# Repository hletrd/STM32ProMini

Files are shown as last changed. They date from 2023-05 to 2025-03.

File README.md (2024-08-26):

# STM32 Pro Mini
- STM32 Pro Mini dev board
  - 17.8 x 33mm size (excluding USB port)
  - 28 GPIOs
- Based on STM32F411CEU6 MCU (100MHz ARM Cortex M4 CPU, 512kB Flash, 128kB SRAM) or STM32F103CxT6 MCU (72MHz ARM Cortex M3 CPU, 64kB/128kB Flash, 20kB SRAM)
  - Virtually support all 48 pin packaged(LQFP48, UFQFPN48, ...) STM32 MCUs.

- Two main devices are being supported as of now, one with STM32F103Cx and the other with STM32F411Cx.

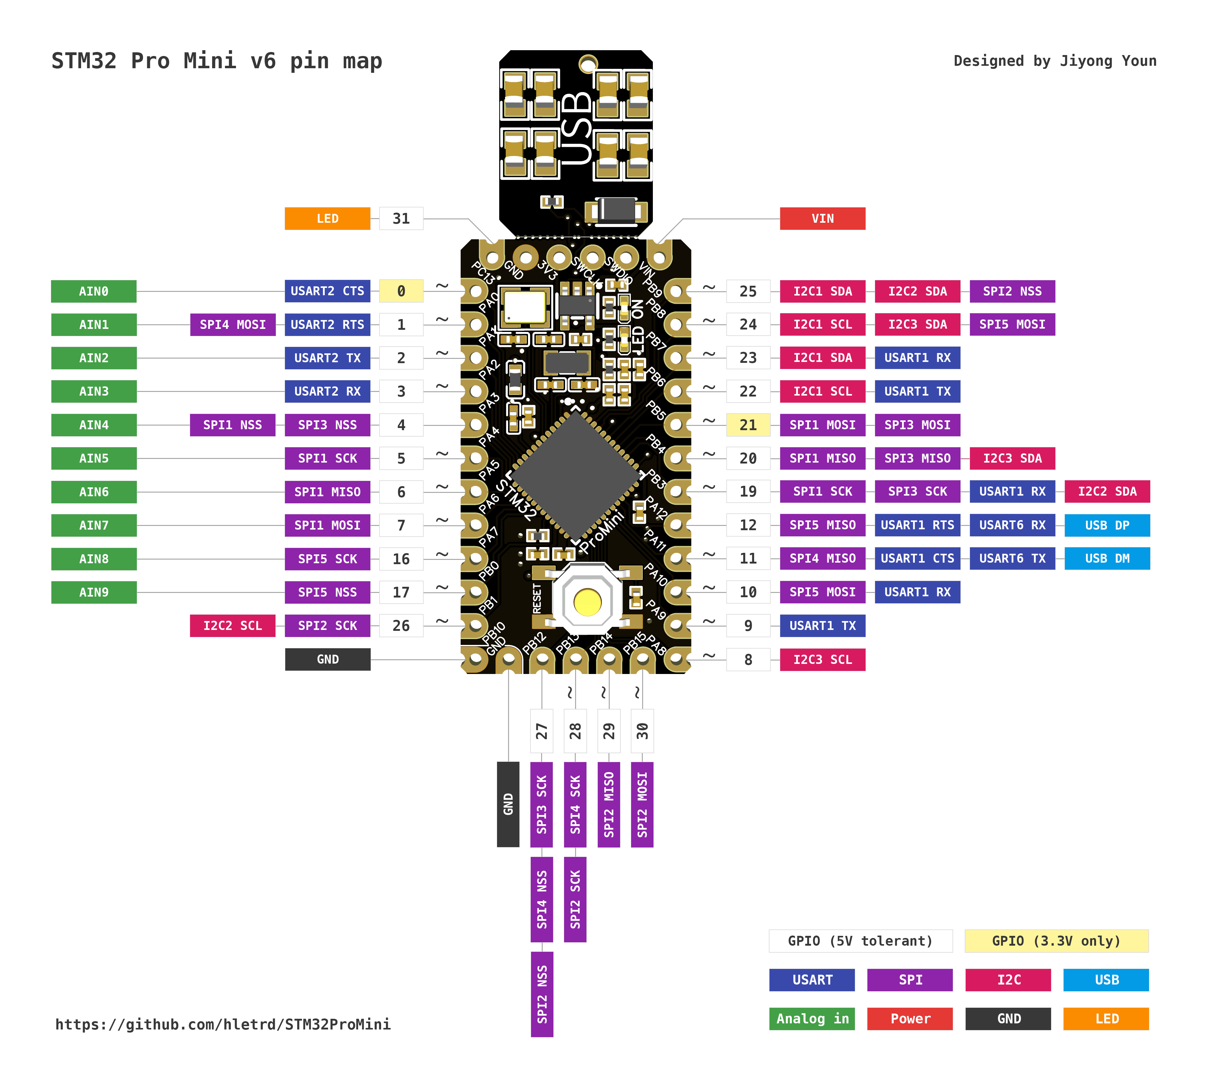
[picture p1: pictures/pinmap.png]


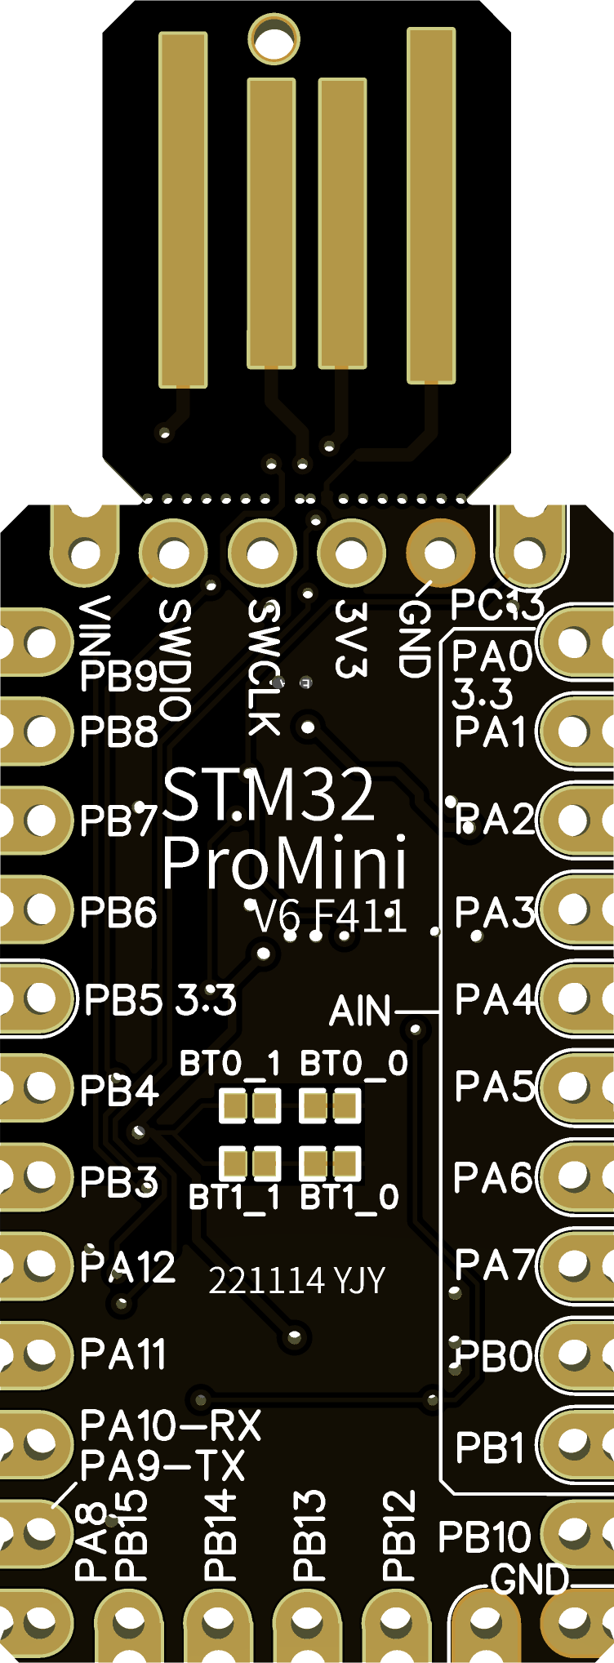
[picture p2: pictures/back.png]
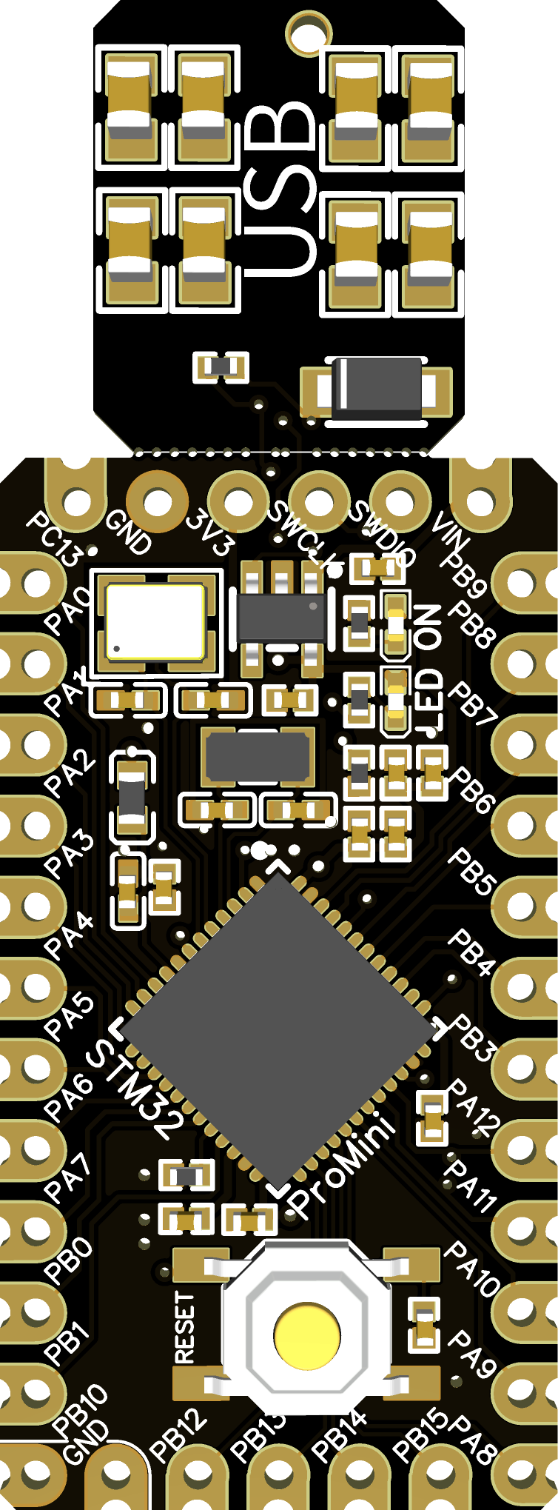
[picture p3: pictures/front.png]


## Getting a board
### Manufacture yourself
  - You can manufacture your own STM32 Pro Mini board with provided files in this repo.
  - Use gerber files in [fabrication/gerber/v6](fabrication/gerber/v6) directory.
  - Use BOM and CPL(Pick&Place) files included in [fabrication](fabrication) directory.
  - Recommended board specifications:
    - Material: FR-4
    - Layers: 2
    - PCB color / silk color: Any
    - Thickness: 1.0mm
    - Surface finish: ENIG
  - All parts can be placed with included BOM/CPL file.

### Get a free board
- Leave an issue and I may send you a free STM32 Pro Mini board.

## Variants and generations
| Gen | CPU | Versions | Features | Board peripheral | Default BOOT configuration |
|-|-|-|-|-|-|
| 1 | STM32F103Cx | V1 (STM32F103C8), V3 (STM32F103CB) | 8MHz ±20ppm HSE, Compatible with common 'Blue Pill' development boards. | None | BOOT0 (0) BOOT1 (0) |
| 2 | STM32F411CE | V2 | 8MHz ±20ppm HSE | Removable USB port | BOOT0 (0) BOOT1 (0) |
| 3 | STM32F411CE | V4, V5, V6 | 12MHz ±10ppm HSE, 32.768kHz ±20ppm LSE (V5, V6), A dedicated analog power rail with noise supression (V5, V6), Castellated edges (V6 only) | Removable USB port | BOOT0 (0) BOOT1 (0) |

### ProMini 3rd gen (F411 (V4, V5, V6))
* Fully redesigned STM32 Pro Mini dev board
* A dedicated analog voltage supply for noise reduction (from V5 and afterwards)
* Ultra low noise, low Iq LDO regulator added to minimize static power draw. (from V5 and afterwards)
* LSE crystal added (from V5 and afterwards)
* PB11 pin is removed and additional GND pin is added.

### ProMini 2nd gen (F411 (V2))
* Based on STM32F411CEU6 MCU 
* PB11 is disabled in this variant, being used to connect a capacitor to supply internal voltage.

#### BOM
* 2.2uF or 4.7uF ceramic capacitor with low ESR have to placed on C13.
* USB pull-up resistor R1 is not needed. (The MCU integrates pull-up resistor for USB D+.)

### ProMini 1st gen (F103 (V1, V3))
* Based on STM32F103C8T6 (V1) / STM32F103CBT6 (V3) MCU
* Compatible with common Blue Pill development board with STM32F103C8T6, except for absence of 32.768kHz crystal.

#### BOM
* C13 is not needed in F103 variant.
* An 1.5k pull-up resistor R1 for USB D+ is needed.

#### Schematic
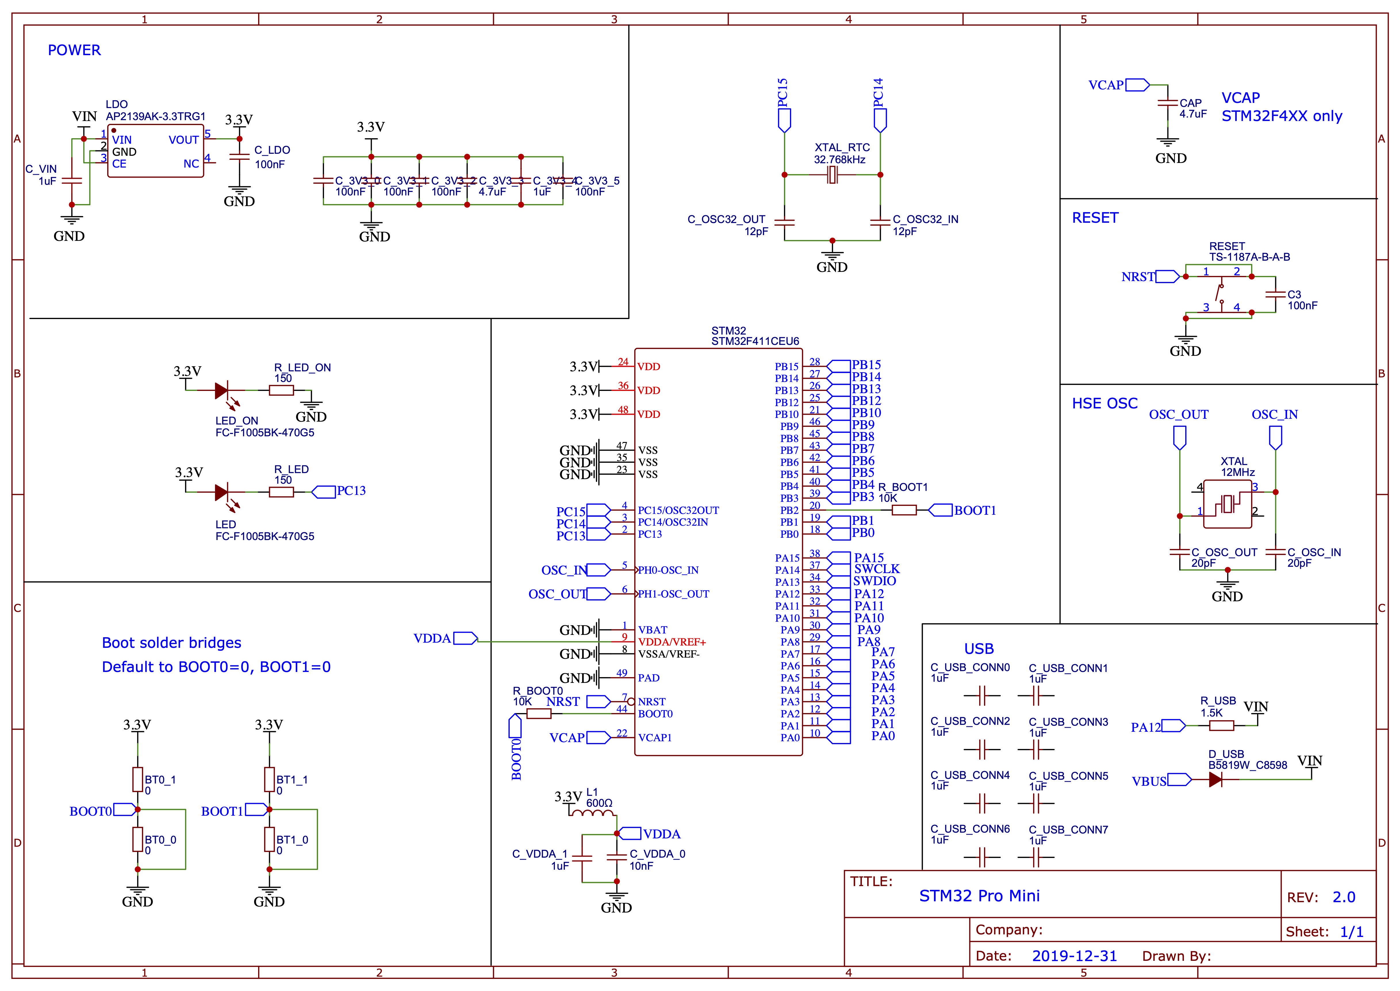
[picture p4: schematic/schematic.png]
Schematic

[PDF version](schematic/schematic.pdf)

#### PCB layout
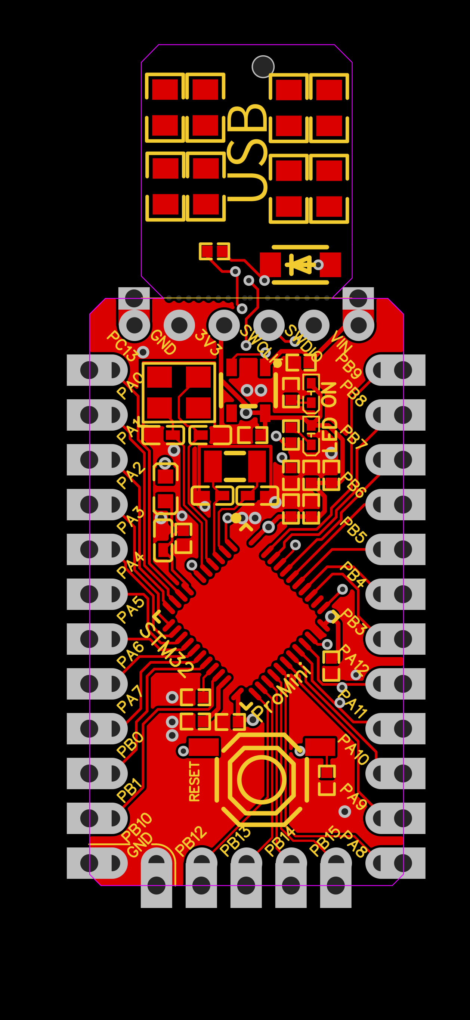
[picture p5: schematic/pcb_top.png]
PCB layout (front)
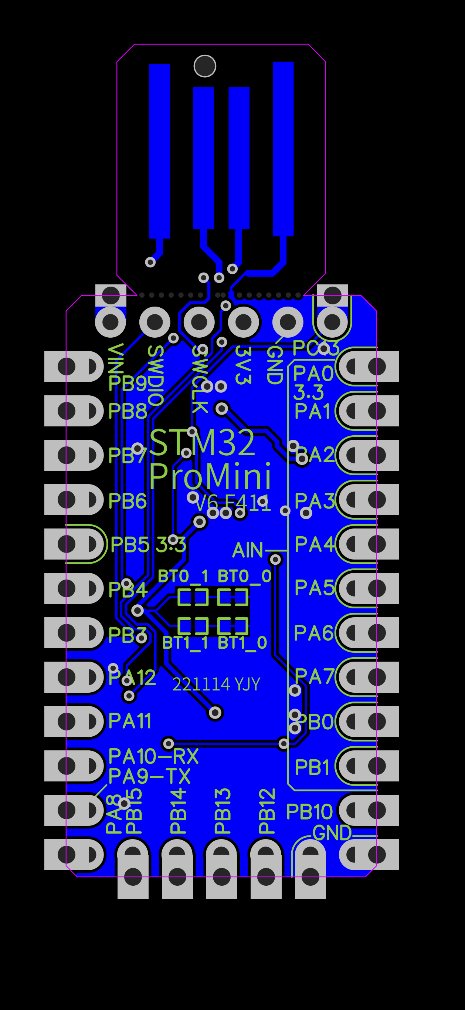
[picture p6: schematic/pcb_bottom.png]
PCB layout (back)


## Setup for Arduino IDE
- Install STM32duino package along with STM32CubeProgrammer.
- Add ```./variants/PROMINI_F411``` (V3-V4) or ```./variants/PROMINI_F411_V5``` (V5, V6)  directory to Arduino IDE ```packages/STM32/hardware/stm32/(version)/variants``` directory.
- Add the content of ```boards-add.txt``` to ```packages/STM32/hardware/stm32/(version)/boards.txt```.

### Programming
- [USB HID bootloader fork](https://github.com/hletrd/STM32_HID_Bootloader) may be used to upload using the integrated USB port.

### Tutorial
- [Getting started with STM32 Pro Mini](TUTORIAL.md)

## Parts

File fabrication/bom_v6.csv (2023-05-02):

ID | Name | Designator | Footprint | Quantity | Manufacturer Part | Manufacturer | Supplier | Supplier Part | Price
1 | 0 | BT0_0,BT0_1,BT1_0,BT1_1 | 0402 | 4 | 0402WGF0000TCE | UniOhm | LCSC | C17168
2 | 1uF | C_USB_CONN4,C_USB_CONN5,C_USB_CONN6,C_USB_CONN7,C_USB_CONN0,C_USB_CONN1,C_USB_CONN2,C_USB_CONN3 | 0805 | 8 | CL21B105KBFNNNE | SAMSUNG | LCSC | C28323 | 0.002
3 | 100nF | C3,C_3V3_0,C_3V3_1,C_3V3_2,C_3V3_5,C_LDO | 0402 | 6 | CL05B104KO5NNNC | SAMSUNG | LCSC | C1525
4 | 4.7uF | CAP,C_3V3_3 | 0402 | 2 | CL05A475MP5NRNC | SAMSUNG | LCSC | C23733 | 0.001
5 | 1uF | C_3V3_4,C_VDDA_1,C_VIN | 0402 | 3 | CL05A105KA5NQNC | SAMSUNG | LCSC | C52923 | 0.001
6 | 12pF | C_OSC32_IN,C_OSC32_OUT | C0402 | 2 | 0402CG120J500NT | FH(风华) | LCSC | C1547
7 | 20pF | C_OSC_IN,C_OSC_OUT | C0402 | 2 | 0402CG200J500NT | FH | LCSC | C1554
8 | 10nF | C_VDDA_0 | C0402 | 1 | CL05B103KB5NNNC | SAMSUNG(三星) | LCSC | C15195
9 | 600Ω | L1 | L0603 | 1 | GZ1608D601TF | Sunlord(顺络) | LCSC | C1002 | 0.001
10 | AP2139AK-3.3TRG1 | LDO | SOT-23-5_L3.0-W1.7-P0.95-LS2.8-BR | 1 | AP2139AK-3.3TRG1 | DIODES | LCSC | C150720 | 0.017
11 | FC-F1005BK-470G5 | LED,LED_ON | LED0402-RD | 2 | FC-F1005BK-470G5 | NATIONSTAR | LCSC | C130724 | 0.006
12 | TS-1187A-B-A-B | RESET | SW-SMD_4P-L5.1-W5.1-P3.70-LS6.5-TL-2 | 1 | TS-1187A-B-A-B | XKB Connectivity(中国星坤) | LCSC | C318884 | 0.003
13 | 10K | R_BOOT0,R_BOOT1 | 0402 | 2 | 0402WGF1002TCE | UniOhm | LCSC | C25744
14 | 150 | R_LED,R_LED_ON | 0402 | 2 | 0402WGF1500TCE | UniOhm | LCSC | C25082
15 | STM32F411CEU6 | STM32 | UFQFPN-48_L7.0-W7.0-P0.50-BL-EP | 1 | STM32F411CEU6 | STMicroelectronics | LCSC | C60420 | 0.672
16 | 12MHz | XTAL | OSC-SMD_4P-L3.2-W2.5-BL | 1 | X322512MSB4SI | YXC(扬兴晶振) | LCSC | C9002 | 0.014
17 | 32.768kHz | XTAL_RTC | FC-135R_L3.2-W1.5 | 1 | Q13FC1350000400 | EPSON(爱普生) | LCSC | C32346 | 0.033
18 | B5819W_C8598 | D_USB | SOD-123_L2.8-W1.8-LS3.7-RD | 1 | B5819W | CJ | LCSC | C8598 | 0.005
19 | 1.5K | R_USB | 0402 | 1 | 0402WGF1501TCE | UniOhm | LCSC | C25867

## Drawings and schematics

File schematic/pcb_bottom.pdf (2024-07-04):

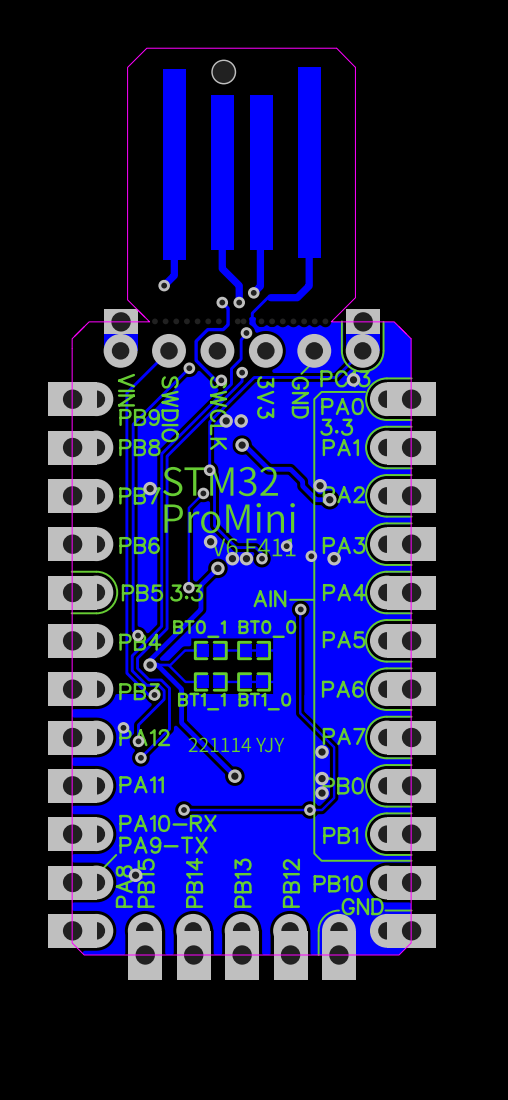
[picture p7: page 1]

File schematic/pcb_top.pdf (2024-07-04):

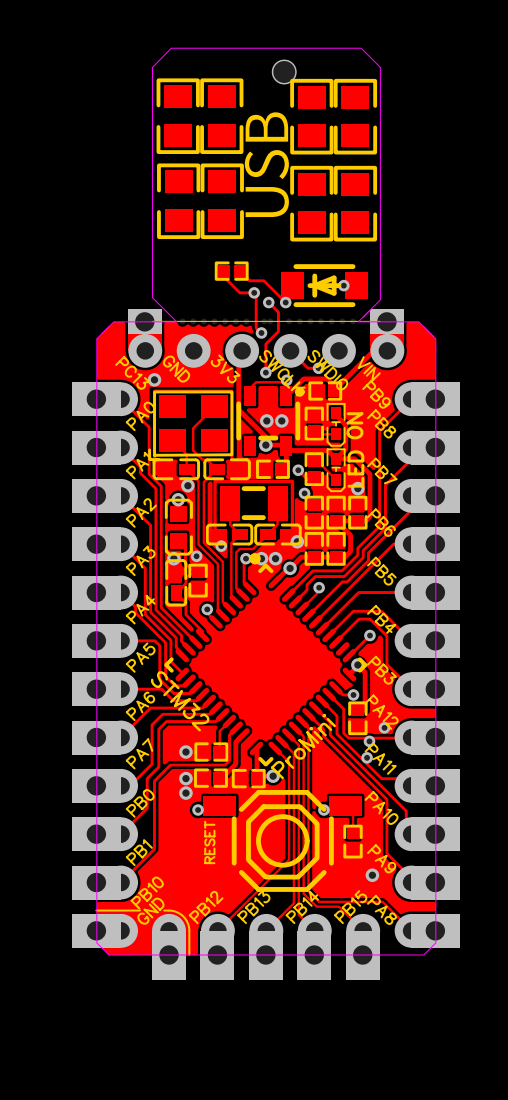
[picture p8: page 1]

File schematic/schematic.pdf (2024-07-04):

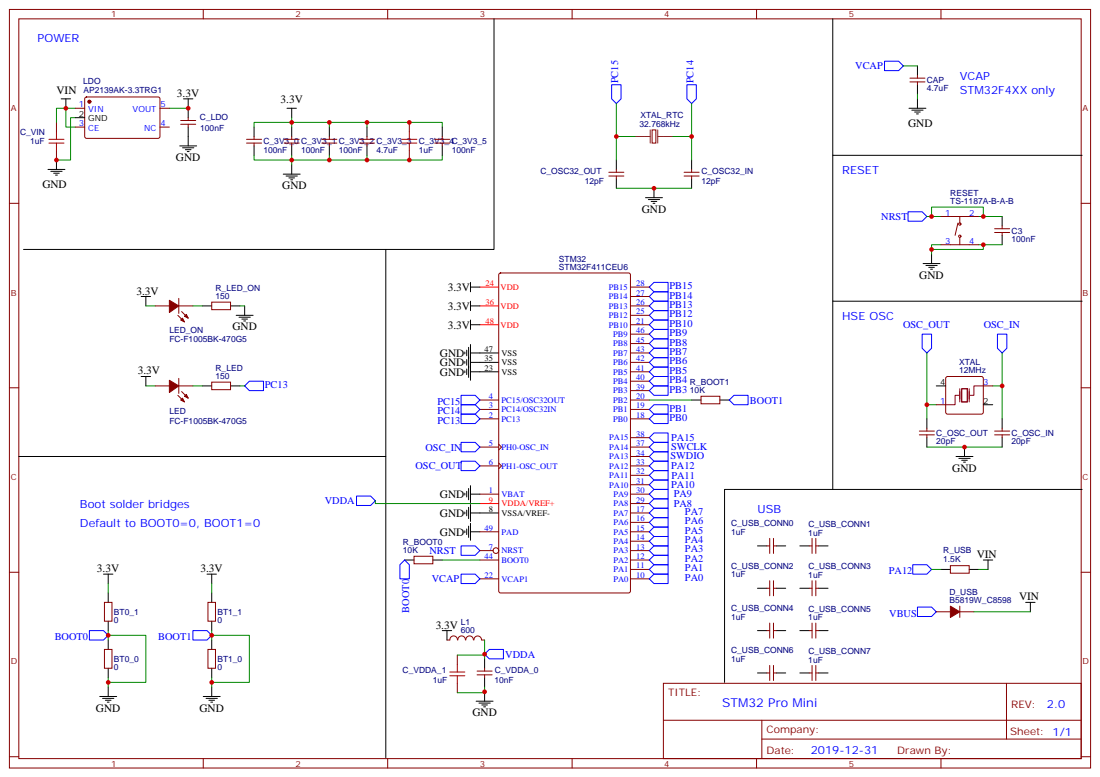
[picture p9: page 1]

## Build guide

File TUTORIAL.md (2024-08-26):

## Setup for Arduino IDE
* What you need:
  * An STM32 ProMini F411CE board.
  * An ST-LINK V2 programmer. Any generic ST-LINK V2 programmer should work, which can be found on eBay or AliExpress.

### Software

#### IDE Setup
- [Download](https://www.arduino.cc/en/software) and install Arduino IDE.
- Download and install STM32duino package.
  * Open Arduino IDE.
  * Open `Preferences`.
  * Add `https://github.com/stm32duino/BoardManagerFiles/raw/main/package_stmicroelectronics_index.json` to `Additional Boards Manager URLs`.
  * Open `Boards Manager`.
  * Search for `STM32 MCU based boards` and install the package.

#### Installing the necessary board configurations
- Open library directory.
  * Windows: `C:\Users\<username>\AppData\Local\Arduino15\packages\STMicroelectronics\hardware\stm32\<version>\`
  * Linux: `~/Arduino15/packages/STMicroelectronics/hardware/stm32/<version>/`
  * macOS: `~/Library/Arduino15/packages/STMicroelectronics/hardware/stm32/<version>/`
- Locate the `boards.txt` file and open it.
- Copy and paste the ENTIRE contents of `arduino/boards-add.txt` from this repository to the `boards.txt` file.
- Save the file.
- Copy and paste the `arduino/variants` folder from this repository to the `variants` folder in the STM32duino package directory.
- Now, you should be able to find the `Custom` boards in the Arduino IDE, and `ProMini F411CE` will appear under the `Board part number` section.

### Wiring
- Connect ST-LINK V2 programmer to the board. Only 4 wires are needed:
  * SWDIO -> SWDIO
  * SWCLK -> SWCLK
  * 3.3V -> 3V3
  * GND -> GND

### Uploading code
- Connect ST-LINK V2 programmer to the computer.
- Write any code, such as
```cpp
// Blink LED on PC3
void setup() {
  pinMode(PC3, OUTPUT);
}

void loop() {
  digitalWrite(PC3, HIGH);
  delay(1000);
  digitalWrite(PC3, LOW);
  delay(1000);
}
```

- Select the board `Custom Boards` and set the board part number to `ProMini F411CE`.
- Make sure that the `Upload method` is set to `STM32CubeProgrammer (SWD)`. `Port` does not matter.
- Now, you can simply upload the code to the board by clicking the `Upload` button.

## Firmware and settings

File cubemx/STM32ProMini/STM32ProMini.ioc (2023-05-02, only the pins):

Mcu.UserName=STM32F411CEUx
PA13.Signal=SYS_JTMS-SWDIO
PA14.Signal=SYS_JTCK-SWCLK
PC14-OSC32_IN.Signal=RCC_OSC32_IN
PC15-OSC32_OUT.Signal=RCC_OSC32_OUT

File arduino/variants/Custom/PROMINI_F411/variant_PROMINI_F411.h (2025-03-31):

/*
 *******************************************************************************
 * Copyright (c) 2020, STMicroelectronics
 * All rights reserved.
 *
 * This software component is licensed by ST under BSD 3-Clause license,
 * the "License"; You may not use this file except in compliance with the
 * License. You may obtain a copy of the License at:
 *                        opensource.org/licenses/BSD-3-Clause
 *
 *******************************************************************************
 */
#pragma once

/*----------------------------------------------------------------------------
 *        STM32 pins number
 *----------------------------------------------------------------------------*/
#define PA0                     PIN_A0
#define PA1                     PIN_A1
#define PA2                     PIN_A2
#define PA3                     PIN_A3
#define PA4                     PIN_A4
#define PA5                     PIN_A5
#define PA6                     PIN_A6
#define PA7                     PIN_A7
#define PA8                     8
#define PA9                     9
#define PA10                    10
#define PA11                    11
#define PA12                    12
#define PA13                    13
#define PA14                    14
#define PA15                    15
#define PB0                     PIN_A8
#define PB1                     PIN_A9
#define PB2                     18
#define PB3                     19
#define PB4                     20
#define PB5                     21
#define PB6                     22
#define PB7                     23
#define PB8                     24
#define PB9                     25
#define PB10                    26
#define PB12                    27
#define PB13                    28
#define PB14                    29
#define PB15                    30
#define PC13                    31
#define PC14                    32
#define PC15                    33
#define PH0                     34
#define PH1                     35

// Alternate pins number
#define PA0_ALT1                (PA0  | ALT1)
#define PA1_ALT1                (PA1  | ALT1)
#define PA2_ALT1                (PA2  | ALT1)
#define PA2_ALT2                (PA2  | ALT2)
#define PA3_ALT1                (PA3  | ALT1)
#define PA3_ALT2                (PA3  | ALT2)
#define PA4_ALT1                (PA4  | ALT1)
#define PA7_ALT1                (PA7  | ALT1)
#define PA15_ALT1               (PA15 | ALT1)
#define PB0_ALT1                (PB0  | ALT1)
#define PB1_ALT1                (PB1  | ALT1)
#define PB3_ALT1                (PB3  | ALT1)
#define PB4_ALT1                (PB4  | ALT1)
#define PB5_ALT1                (PB5  | ALT1)
#define PB8_ALT1                (PB8  | ALT1)
#define PB9_ALT1                (PB9  | ALT1)
#define PB12_ALT1               (PB12 | ALT1)
#define PB13_ALT1               (PB13 | ALT1)

#define NUM_DIGITAL_PINS        36
#define NUM_ANALOG_INPUTS       10

// On-board LED pin number
#ifndef LED_BUILTIN
  #define LED_BUILTIN           PC13
#endif

// On-board user button
#ifndef USER_BTN
  #define USER_BTN              PNUM_NOT_DEFINED
#endif

// SPI definitions
#ifndef PIN_SPI_SS
  #define PIN_SPI_SS            PB12_ALT1
#endif
#ifndef PIN_SPI_SS1
  #define PIN_SPI_SS1           PNUM_NOT_DEFINED
#endif
#ifndef PIN_SPI_SS2
  #define PIN_SPI_SS2           PNUM_NOT_DEFINED
#endif
#ifndef PIN_SPI_SS3
  #define PIN_SPI_SS3           PNUM_NOT_DEFINED
#endif
#ifndef PIN_SPI_MOSI
  #define PIN_SPI_MOSI          PA1
#endif
#ifndef PIN_SPI_MISO
  #define PIN_SPI_MISO          PA11
#endif
#ifndef PIN_SPI_SCK
  #define PIN_SPI_SCK           PB13_ALT1
#endif

// I2C definitions
#ifndef PIN_WIRE_SDA
  #define PIN_WIRE_SDA          PB3
#endif
#ifndef PIN_WIRE_SCL
  #define PIN_WIRE_SCL          PB10
#endif

// Timer Definitions
// Use TIM6/TIM7 when possible as servo and tone don't need GPIO output pin
#ifndef TIMER_TONE
  #define TIMER_TONE            TIM10
#endif
#ifndef TIMER_SERVO
  #define TIMER_SERVO           TIM11
#endif

// UART Definitions
#ifndef SERIAL_UART_INSTANCE
  #define SERIAL_UART_INSTANCE  2
#endif

// Default pin used for generic 'Serial' instance
// Mandatory for Firmata
#ifndef PIN_SERIAL_RX
  #define PIN_SERIAL_RX         PA3
#endif
#ifndef PIN_SERIAL_TX
  #define PIN_SERIAL_TX         PA2
#endif

// Extra HAL modules

#ifndef HSE_VALUE
  #define HSE_VALUE             12000000U
#endif

#define HAL_TIM_MODULE_ENABLED
#define HAL_SPI_MODULE_ENABLED

/*----------------------------------------------------------------------------
 *        Arduino objects - C++ only
 *----------------------------------------------------------------------------*/

#ifdef __cplusplus
  // These serial port names are intended to allow libraries and architecture-neutral
  // sketches to automatically default to the correct port name for a particular type
  // of use.  For example, a GPS module would normally connect to SERIAL_PORT_HARDWARE_OPEN,
  // the first hardware serial port whose RX/TX pins are not dedicated to another use.
  //
  // SERIAL_PORT_MONITOR        Port which normally prints to the Arduino Serial Monitor
  //
  // SERIAL_PORT_USBVIRTUAL     Port which is USB virtual serial
  //
  // SERIAL_PORT_LINUXBRIDGE    Port which connects to a Linux system via Bridge library
  //
  // SERIAL_PORT_HARDWARE       Hardware serial port, physical RX & TX pins.
  //
  // SERIAL_PORT_HARDWARE_OPEN  Hardware serial ports which are open for use.  Their RX & TX
  //                            pins are NOT connected to anything by default.
  #ifndef SERIAL_PORT_MONITOR
    #define SERIAL_PORT_MONITOR   Serial
  #endif
  #ifndef SERIAL_PORT_HARDWARE
    #define SERIAL_PORT_HARDWARE  Serial
  #endif
#endif

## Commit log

2019-12-31 Added unzipped gerber
    [Gerber_BoardOutline.GKO, Gerber_BottomLayer.GBL, Gerber_BottomPasteMaskLayer.GBP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]
2020-01-01 updated board design
    [Gerber_BoardOutline.GKO, Gerber_BottomLayer.GBL, Gerber_BottomPasteMaskLayer.GBP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]
2020-03-24 Update fabrication files
    [Gerber_BoardOutline.GKO, Gerber_BottomLayer.GBL, Gerber_BottomPasteMaskLayer.GBP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]
2022-11-28 updates for v4/v5x
    [Drill_NPTH_Through.DRL, Drill_PTH_Through.DRL, Drill_PTH_Through_Via.DRL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]
2023-05-02 Update v6 files and readme
    [Drill_NPTH_Through.DRL, Drill_PTH_Through.DRL, Drill_PTH_Through_Via.DRL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]
2023-05-02 Add STM32CubeMX project files
2023-05-03 add pwm to pinmap
2024-07-04 add schematic
2024-07-04 add pcb layout files
2025-04-01 update boards.txt config
